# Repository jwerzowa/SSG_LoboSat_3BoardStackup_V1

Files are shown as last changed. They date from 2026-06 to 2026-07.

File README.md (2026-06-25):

# LOBOSAT 3-Board PCB Stackup V1

KiCad PCB designs for the LOBOSAT CubeSat, developed as part of UNM's satellite club (LOBOSAT/SSG).
Reach out to Julien Werzowa for any questions. 

## Board Overview

Boards:   

| `Feather_IMU_Board - Telemetry` : Adafruit Feather M0 RFM95 + Sparkfun ICM-20948 9-DOF IMU |  
| `Raspberry_PI_Board - Videography` : Raspberry Pi Zero 2W compute board use for Videography |  
| `Lightracker_Battery_Board - Power & GPS` : LightTracker + DFR1015 buck converter (7.4V → 5V) |     

## Power Architecture

7.4V LiPo → DFR1015 buck converter → 5V rail distributed across all three boards via 2×8 dual-row headers.

## Tools

- KiCad 9
- Fabrication: JCLPCB

## Status

V1 — initial commit. Work in progress.

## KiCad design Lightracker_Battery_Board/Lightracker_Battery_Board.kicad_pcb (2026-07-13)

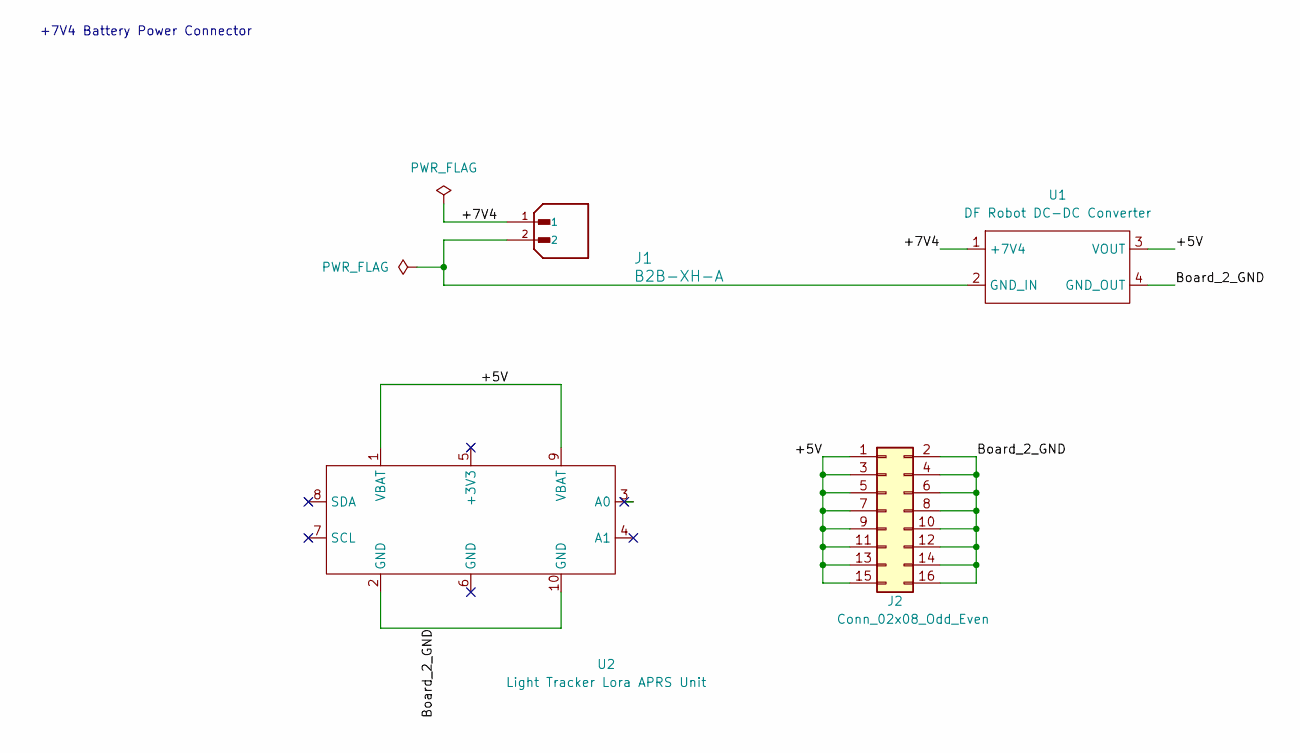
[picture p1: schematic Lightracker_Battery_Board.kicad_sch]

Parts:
J1: B2B-XH-A; JST_XH_B2B-XH-A_1x02_P2.50mm_Vertical; PARTREV N/A
J2: Conn_02x08_Odd_Even; PinHeader_2x08_P2.54mm_Vertical
U1: DF Robot DC-DC Converter; Sat_Club_Buck_Converter
U2: Light Tracker Lora APRS Unit; Light_Tracker

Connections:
/+5V: J2.1, J2.3, J2.5, J2.7, J2.9, J2.11, J2.13, J2.15, U1.3 (VOUT), U2.1 (VBAT), U2.9 (VBAT)
/+7V4: J1.1, U1.1 (+7V4)
/Board_2_GND: J2.2, J2.4, J2.6, J2.8, J2.10, J2.12, J2.14, J2.16, U1.4 (GND_OUT), U2.2 (GND), U2.10 (GND)
unnamed: J1.2, U1.2 (GND_IN)

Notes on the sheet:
+7V4 Battery Power Connector

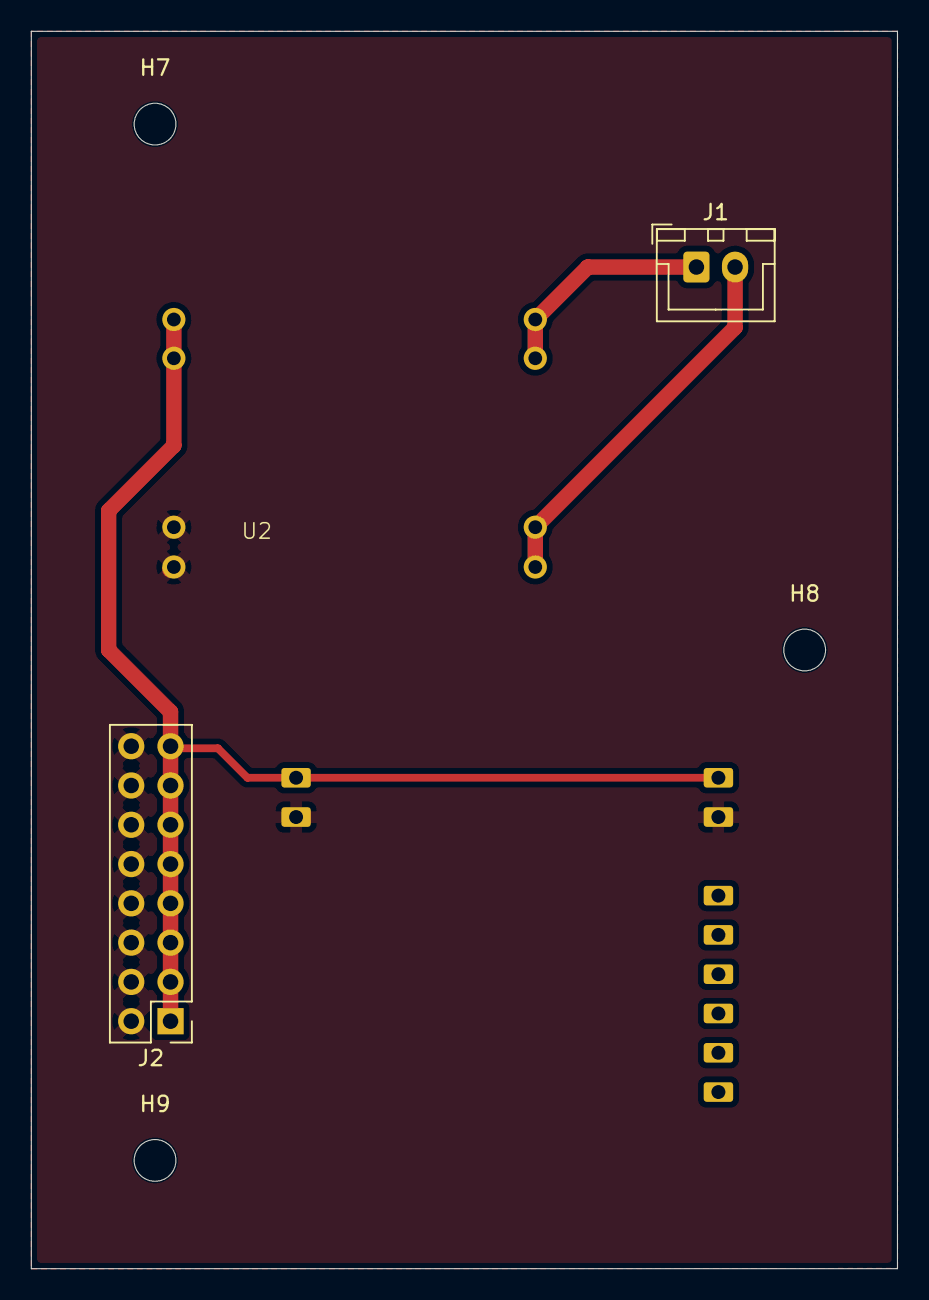
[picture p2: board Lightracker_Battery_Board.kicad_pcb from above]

Board: 2 copper layers, 56.0 x 80.0 mm, 7 parts (1 on the bottom side), 4 nets.

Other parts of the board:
H7, H8, H9: MountingHole_2.7mm_M2.5

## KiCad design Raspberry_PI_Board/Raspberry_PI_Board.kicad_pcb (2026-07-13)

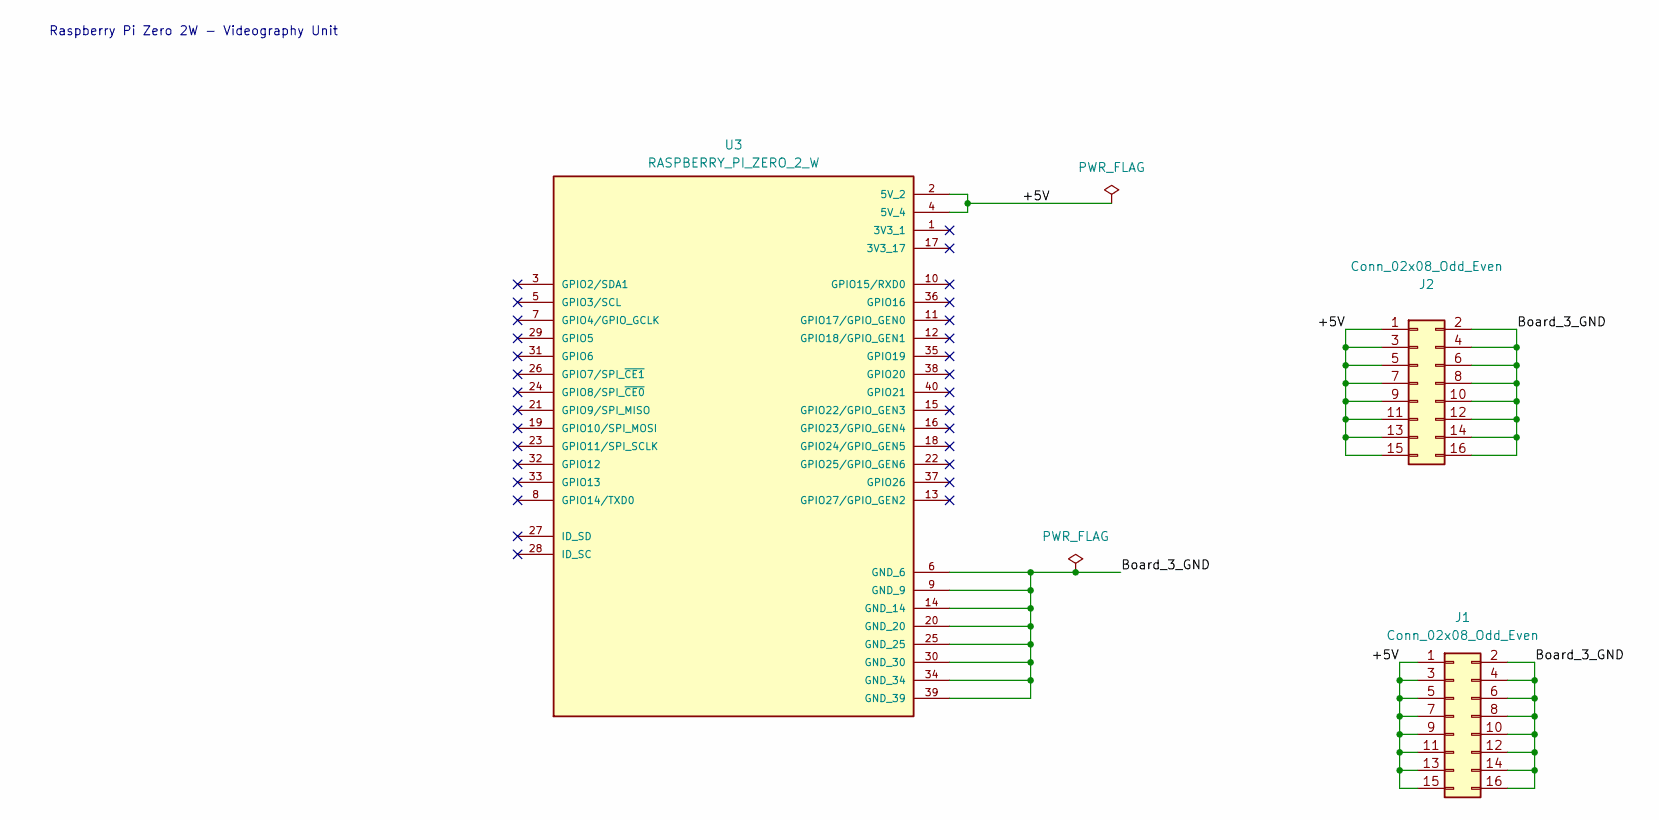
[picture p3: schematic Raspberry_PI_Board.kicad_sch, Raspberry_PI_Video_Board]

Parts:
J1, J2: Conn_02x08_Odd_Even; PinHeader_2x08_P2.54mm_Vertical
U3: RASPBERRY_PI_ZERO_2_W; Raspberry_Pi_Zero_Socketed_THT_FaceDown_MountingHoles; PARTREV April 2024

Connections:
/+5V: J1.1, J1.3, J1.5, J1.7, J1.9, J1.11, J1.13, J1.15, J2.1, J2.3, J2.5, J2.7, J2.9, J2.11, J2.13, J2.15, U3.2 (5V_2), U3.4 (5V_4)
/Board_3_GND: J1.2, J1.4, J1.6, J1.8, J1.10, J1.12, J1.14, J1.16, J2.2, J2.4, J2.6, J2.8, J2.10, J2.12, J2.14, J2.16, U3.6 (GND_6), U3.9 (GND_9), U3.14 (GND_14), U3.20 (GND_20), U3.25 (GND_25), U3.30 (GND_30), U3.34 (GND_34), U3.39 (GND_39)

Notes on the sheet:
Raspberry Pi Zero 2W - Videography Unit

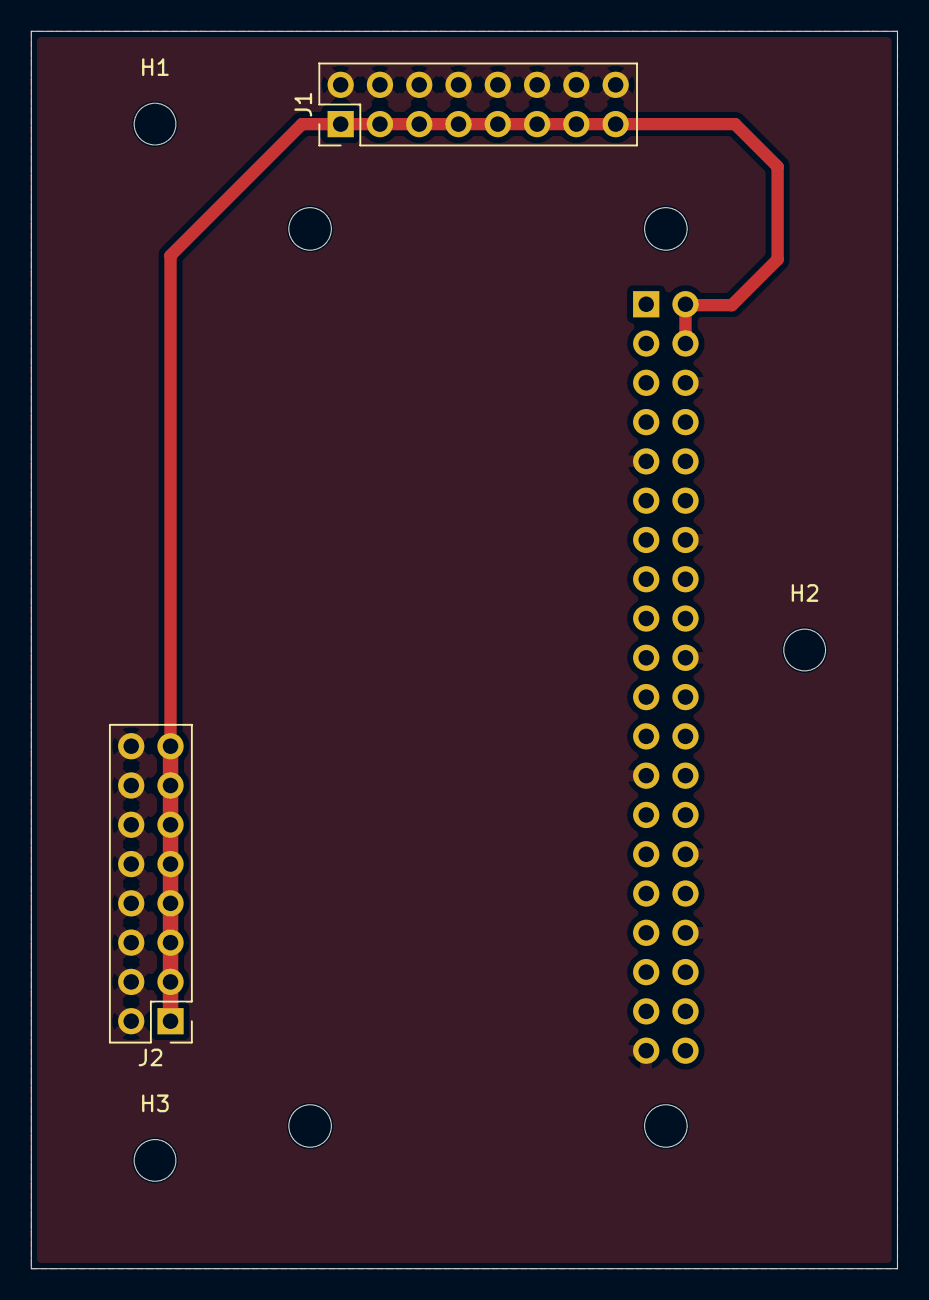
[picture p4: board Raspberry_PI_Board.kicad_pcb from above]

Board: 2 copper layers, 56.0 x 80.0 mm, 6 parts (1 on the bottom side), 2 nets.

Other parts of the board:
H1, H2, H3: MountingHole_2.7mm_M2.5

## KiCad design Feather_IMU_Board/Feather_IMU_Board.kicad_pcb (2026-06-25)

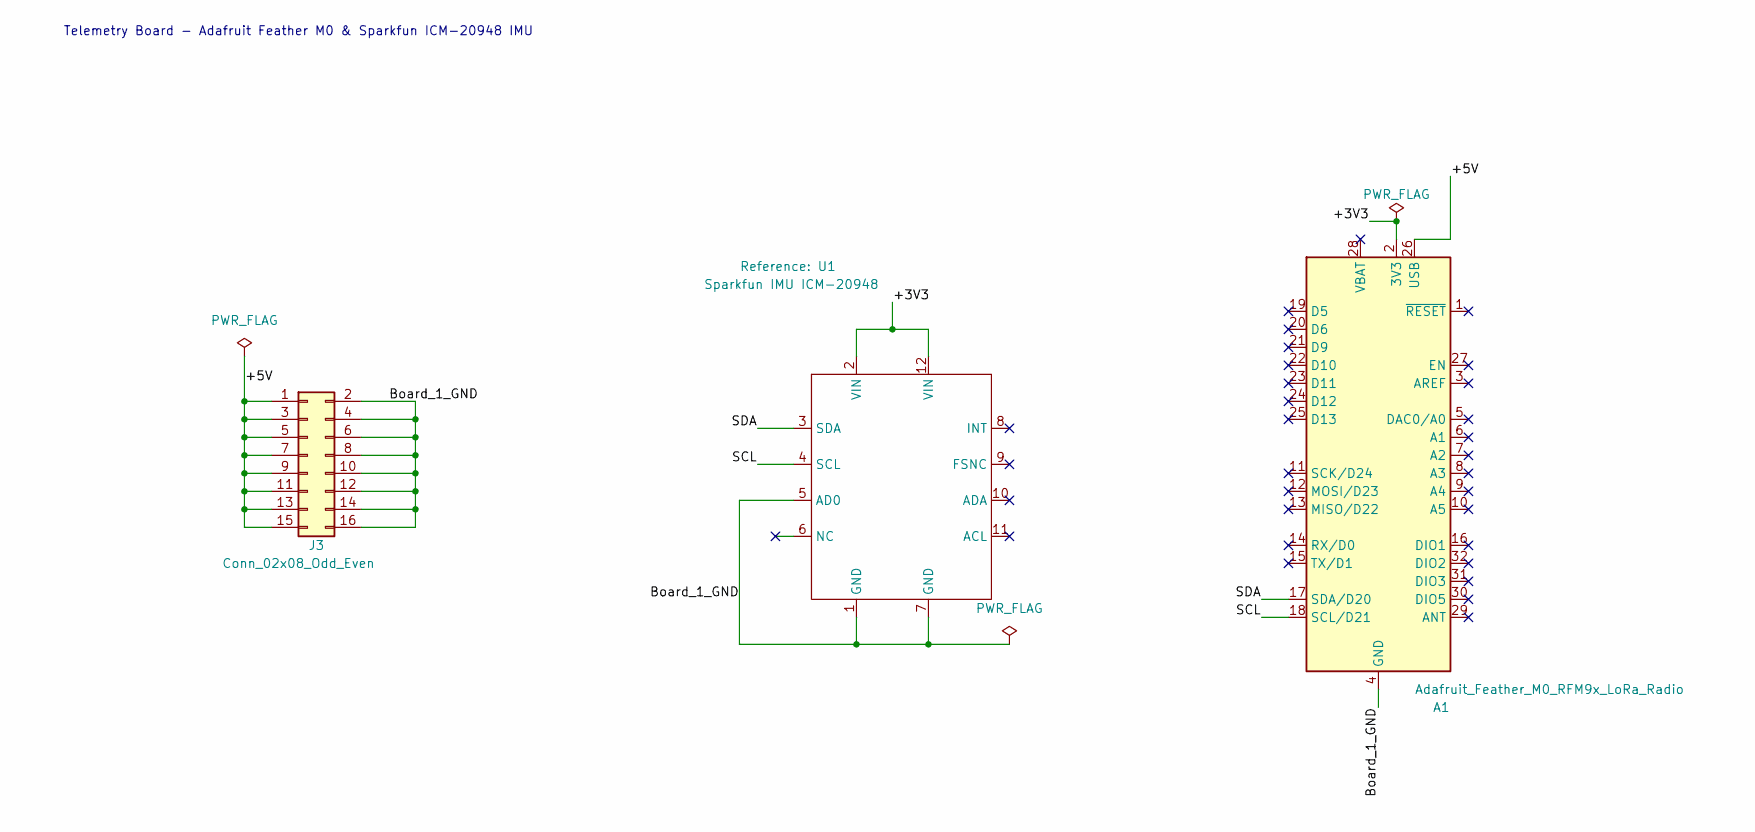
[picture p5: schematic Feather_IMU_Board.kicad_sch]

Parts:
A1: Adafruit_Feather_M0_RFM9x_LoRa_Radio; Adafruit_Feather_M0_RFM
J3: Conn_02x08_Odd_Even; PinHeader_2x08_P2.54mm_Vertical
U1: Sparkfun IMU ICM-20948; SparkFun_ICM20948_Breakout_2x06_23mm

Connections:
/+3V3: A1.2 (3V3), U1.2 (VIN), U1.12 (VIN)
/+5V: A1.26 (USB), J3.1, J3.3, J3.5, J3.7, J3.9, J3.11, J3.13, J3.15
/Board_1_GND: A1.4 (GND), J3.2, J3.4, J3.6, J3.8, J3.10, J3.12, J3.14, J3.16, U1.1 (GND), U1.5 (AD0), U1.7 (GND)
/SCL: A1.18 (SCL/D21), U1.4 (SCL)
/SDA: A1.17 (SDA/D20), U1.3 (SDA)

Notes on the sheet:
Telemetry Board - Adafruit Feather M0 & Sparkfun ICM-20948 IMU

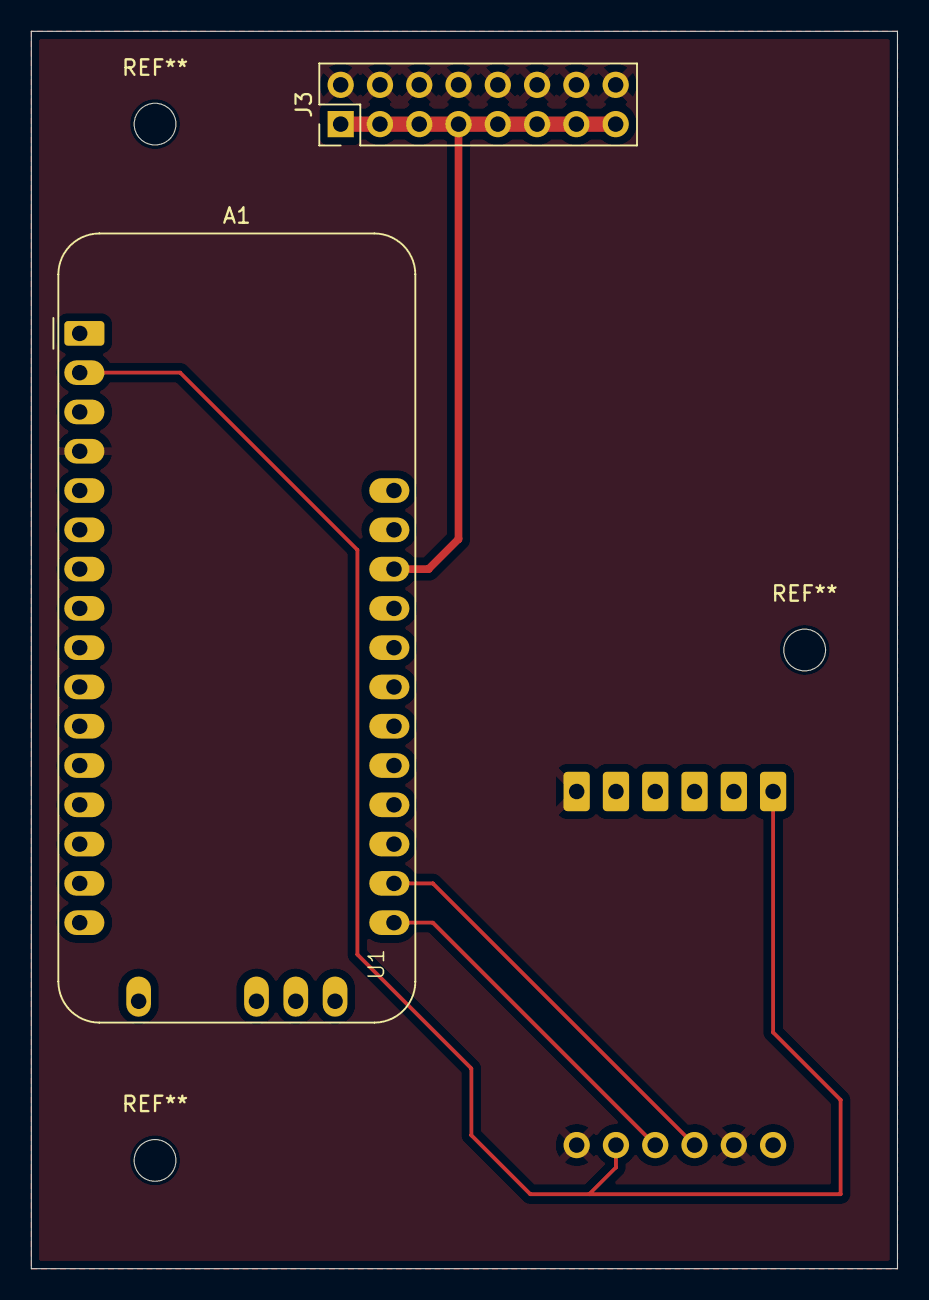
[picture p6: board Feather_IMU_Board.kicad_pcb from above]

Board: 2 copper layers, 56.0 x 80.0 mm, 3 parts (0 on the bottom side), 5 nets.

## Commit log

2026-06-25 Create README.md for LOBOSAT 3-Board PCB Stackup
    Added initial README.md with project overview and details.
2026-06-25 Fix formatting in Board Overview section of README
2026-06-25 Update KiCad version and fabrication source
    Updated KiCad version and fabrication source in README.
2026-06-25 Revise board overview section in README
    Updated board descriptions to use table format for clarity.
2026-06-25 Fix formatting in README for board descriptions
2026-07-13 Fix flipped components
    [Lightracker_Battery_Board.kicad_pcb, Lightracker_Battery_Board.kicad_sch, Raspberry_PI_Board.kicad_pcb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]
